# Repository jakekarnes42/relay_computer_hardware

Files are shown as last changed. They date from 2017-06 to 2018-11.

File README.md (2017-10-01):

# Relay Computer (Hardware)
This repo contains the hardware information for a computer constructed out of relays. Its software companion project can be found [here](https://github.com/jakekarnes42/relay_computer_software). 

This project has taken much of its inspiration from Dr. Harry Porter's [relay computer](https://web.cecs.pdx.edu/~harry/Relay/RelayPaper.htm). While there are many architectural similarities, there are also significant differences which are described below. This project wouldn't have been possible for me without his clear notes and thorough explanations. 

The documentation is still a work in progress and likely to change as the design itself changes. 

## Hardware Architecture Notes:
### Registers:
All registers are 16 bits (1 word) wide. There are 11 registers total.

There are 5 general purpose registers: AX, BX, CX, DX, and EX. These registers don’t have any special functions (e.g. stack operations). 

There are 2 stack-pointer registers: SP and RP. These are used with the PUSH, POP, CALL and CALL_I operations. These registers point to memory locations of the current top of the stack. When a value is pushed onto the stack, the register is first incremented, and then the value is copied to that location in memory. When a value is to popped off the stack, the value in the memory address pointed to by the stack register is returned, and then the stack register is decremented. 

There is one program counter: PC. The PC contains the address of the next
instruction to be executed. In some computers, this register is called the “Instruction Pointer”.

There is one instruction register: INST. During instruction execution, INST contains the current instruction being executed.

There are two temporary registers: TMP1 and TMP2. These are considered “scratch pads” and their values are not to be considered consistent between instructions. These are the inputs to the ALU. 
### Condition Codes:
####  Zero: 
True (1) when the ALU output is zero. If any bit of the ALU output is 1, then this flag will be set to false (0).
Sign:
True (1) when the highest (16th) bit of the ALU output is 1. That is, if considered as a signed value, the flag is set to true when the ALU output is negative. 
#### Overflow:
True (1) when the ALU output produced a signed overflow. Overflow occurs if the addition of two positive numbers gives a negative number and if the addition of two negative numbers gives a positive. That is, you need to compare the MSB of the operands and the answer. If the sign of the operands and the sign of the answer don't match, the overflow flag is turned on. The output is too large or too small to store in 16 bits (using two’s-complement format)

If the ALU isn’t performing ADD, INC, or DEC, this should be false (0), since it doesn’t really make sense for a logic operation to result in overflow
#### Carry:
This is the value of the 17th bit of the output. If performing unsigned addition, this indicates that the result was too large to fit into a 16-bit word (i.e. too large to fit into a register). If performing subtraction (e.g. a−b), the carry bit is equivalent to a < b.

If the ALU isn’t performing ADD, INC, or DEC, this should be false (0).
Memory:
The computer has 1,048,576 bits (1 Mb) of random access memory. This is organized as 65,536 (64k) words of 16 bits each. This results in 16-bit addresses, each storing a 16-bit word. 

The memory is non-volatile, i.e. the memory isn’t cleared when the computer is powered off. The program can be loaded into memory separately before the computer is powered on. 
#### ALU:
The ALU takes 3 inputs: a 3-bit function code, and two 16-bit operands. The ALU produces 5 outputs: the zero flag, the sign flag, the overflow flag, the carry flag, and a 16-bit result. 

The 3 bit function code is interpreted as follows:
* 000: INC
* 001: DEC
* 010: ADD
* 011: AND
* 100: OR
* 101: XOR
* 110: NOT
* 111: SHL

##### Design: 
4-bit ALU Schematic

## Changes from Harry’s Design
### Definite
* Dedicated stack register(s)
* I/O device support
* Four ALU-set flags:
1.  s (sign)
2.  z (zero)
3. c (carry)
4.  o (overflow) ** ← NEW**
### Maybe
* TMP registers?
   These aren’t addressable by themselves, but are intermediates for other operations. For example, two TMP registers could be used as the inputs to the ALU. The real operand(s) would be moved into the TMP registers before the ALU is engaged
* Split ALU: single operand instructions vs double operand instructions
   The Arithmetic side should support ADD, INC, DEC. These can all use the Zuse adder with different input C, or 1, or -1
   The Logic side should support AND, OR, XOR, NOT, ROL

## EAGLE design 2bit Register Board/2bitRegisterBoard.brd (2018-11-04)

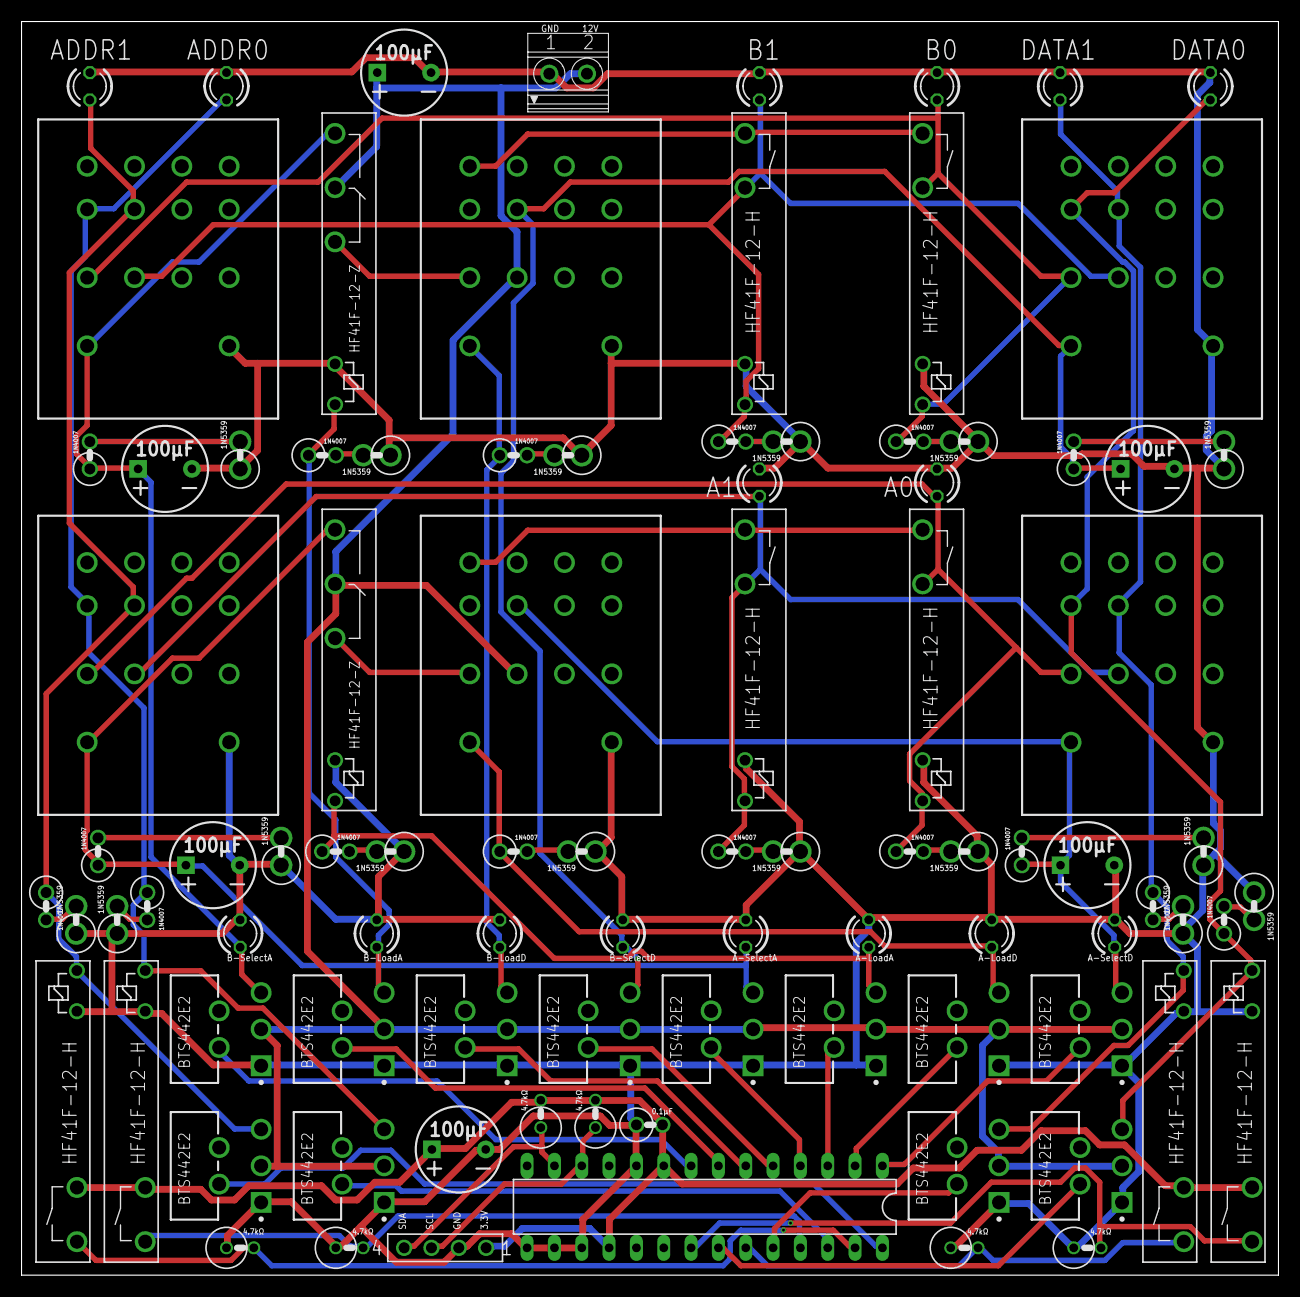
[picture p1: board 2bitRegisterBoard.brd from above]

Board: 2 copper layers, 116.8 x 116.5 mm, 92 parts (0 on the bottom side), 57 nets.

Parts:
12V_PWR_BLK:C1: 100uF; CPOL-RADIAL-5MM-8MM
12V_PWR_BLK:PWR: PWR_BLK; 1751248
COMP_SIGNALS1:3V3_TO_12_1BIT0:U1, COMP_SIGNALS1:3V3_TO_12_1BIT1:U1, COMP_SIGNALS1:3V3_TO_12_1BIT2:U1, COMP_SIGNALS1:3V3_TO_12_1BIT3:U1, COMP_SIGNALS1:3V3_TO_12_1BIT4:U1, COMP_SIGNALS1:3V3_TO_12_1BIT5:U1, COMP_SIGNALS1:3V3_TO_12_1BIT6:U1, COMP_SIGNALS1:3V3_TO_12_1BIT7:U1, COMP_SIGNALS1:DUAL_12V⇆3V3_1BIT0:3V3_TO_12_1BIT1:U1, COMP_SIGNALS1:DUAL_12V⇆3V3_1BIT1:3V3_TO_12_1BIT1:U1, COMP_SIGNALS1:DUAL_12V⇆3V3_1BIT2:3V3_TO_12_1BIT1:U1, COMP_SIGNALS1:DUAL_12V⇆3V3_1BIT3:3V3_TO_12_1BIT1:U1: BTS442E2; TO170P440X1000X1975-5B
COMP_SIGNALS1:DUAL_12V⇆3V3_1BIT0:12V_TO_3V3_1BIT1:D5, COMP_SIGNALS1:DUAL_12V⇆3V3_1BIT1:12V_TO_3V3_1BIT1:D5, COMP_SIGNALS1:DUAL_12V⇆3V3_1BIT2:12V_TO_3V3_1BIT1:D5, COMP_SIGNALS1:DUAL_12V⇆3V3_1BIT3:12V_TO_3V3_1BIT1:D5: 1N4007; RAD2,5
COMP_SIGNALS1:DUAL_12V⇆3V3_1BIT0:12V_TO_3V3_1BIT1:D6, COMP_SIGNALS1:DUAL_12V⇆3V3_1BIT1:12V_TO_3V3_1BIT1:D6, COMP_SIGNALS1:DUAL_12V⇆3V3_1BIT2:12V_TO_3V3_1BIT1:D6, COMP_SIGNALS1:DUAL_12V⇆3V3_1BIT3:12V_TO_3V3_1BIT1:D6: 1N5359VERT_SML; RAD2.5_D2
COMP_SIGNALS1:DUAL_12V⇆3V3_1BIT0:12V_TO_3V3_1BIT1:K3, COMP_SIGNALS1:DUAL_12V⇆3V3_1BIT1:12V_TO_3V3_1BIT1:K3, COMP_SIGNALS1:DUAL_12V⇆3V3_1BIT2:12V_TO_3V3_1BIT1:K3, COMP_SIGNALS1:DUAL_12V⇆3V3_1BIT3:12V_TO_3V3_1BIT1:K3: HF41F-12-H
COMP_SIGNALS1:I2C_IO:C1: 100uF; CPOL-RADIAL-5MM-8MM
COMP_SIGNALS1:I2C_IO:C2: 0.1UF; VERT_CAP
COMP_SIGNALS1:I2C_IO:IC1: MCP23017SP; DIL28-3
COMP_SIGNALS1:I2C_IO:R1, COMP_SIGNALS1:I2C_IO:R2, COMP_SIGNALS1:I2C_IO:R3, COMP_SIGNALS1:I2C_IO:R4, COMP_SIGNALS1:I2C_IO:R5, COMP_SIGNALS1:I2C_IO:R6: 4.7KOHM; RAD2.5_RES
COMP_SIGNALS1:I2C_IO:SV1: FE04-1
COMP_SIGNALS1:LED0, COMP_SIGNALS1:LED1, COMP_SIGNALS1:LED2, COMP_SIGNALS1:LED3, COMP_SIGNALS1:LED4, COMP_SIGNALS1:LED5, COMP_SIGNALS1:LED6, COMP_SIGNALS1:LED7, COMP_SIGNALS1:LED8, COMP_SIGNALS1:LED9, COMP_SIGNALS1:LED10, COMP_SIGNALS1:LED11: LED3MM
REGISTER_A:C1, REGISTER_A:C2: 100uF; CPOL-RADIAL-5MM-8MM
REGISTER_A:D1, REGISTER_A:D3, REGISTER_A:D7, REGISTER_A:D9: 1N4007; RAD2,5
REGISTER_A:D2, REGISTER_A:D4, REGISTER_A:D8, REGISTER_A:D10: 1N5359VERT_SML; RAD2.5_D2
REGISTER_A:ENABLE_ADDRESS:D1: 1N4007; RAD2,5
REGISTER_A:ENABLE_ADDRESS:D2: 1N5359VERT_SML; RAD2.5_D2
REGISTER_A:ENABLE_ADDRESS:K1: PY14-02
REGISTER_A:ENABLE_DATA:D1: 1N4007; RAD2,5
REGISTER_A:ENABLE_DATA:D2: 1N5359VERT_SML; RAD2.5_D2
REGISTER_A:ENABLE_DATA:K1: PY14-02
REGISTER_A:K1: HF41F-12-Z
REGISTER_A:K2: PY14-02
REGISTER_A:K4, REGISTER_A:K5: HF41F-12-H
REGISTER_A:LED2, REGISTER_A:LED3: LED3MM
REGISTER_B:C1, REGISTER_B:C2: 100uF; CPOL-RADIAL-5MM-8MM
REGISTER_B:D1, REGISTER_B:D3, REGISTER_B:D7, REGISTER_B:D9: 1N4007; RAD2,5
REGISTER_B:D2, REGISTER_B:D4, REGISTER_B:D8, REGISTER_B:D10: 1N5359VERT_SML; RAD2.5_D2
REGISTER_B:ENABLE_ADDRESS:D1: 1N4007; RAD2,5
REGISTER_B:ENABLE_ADDRESS:D2: 1N5359VERT_SML; RAD2.5_D2
REGISTER_B:ENABLE_ADDRESS:K1: PY14-02
REGISTER_B:ENABLE_DATA:D1: 1N4007; RAD2,5
REGISTER_B:ENABLE_DATA:D2: 1N5359VERT_SML; RAD2.5_D2
REGISTER_B:ENABLE_DATA:K1: PY14-02
REGISTER_B:K1: HF41F-12-Z
REGISTER_B:K2: PY14-02
REGISTER_B:K4, REGISTER_B:K5: HF41F-12-H
REGISTER_B:LED2, REGISTER_B:LED3: LED3MM

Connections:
+3V3: COMP_SIGNALS1:DUAL_12V⇆3V3_1BIT0:12V_TO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.4, COMP_SIGNALS1:DUAL_12V⇆3V3_1BIT1:12V_TO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.4, COMP_SIGNALS1:DUAL_12V⇆3V3_1BIT2:12V_TO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.4, COMP_SIGNALS1:DUAL_12V⇆3V3_1BIT3:12V_TO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.4, COMP_SIGNALS1:I2C_IO:C1.1, COMP_SIGNALS1:I2C_IO:C2.A, COMP_SIGNALS1:I2C_IO:IC1.9, COMP_SIGNALS1:I2C_IO:IC1.18, COMP_SIGNALS1:I2C_IO:R1.A, COMP_SIGNALS1:I2C_IO:R2.A, COMP_SIGNALS1:I2C_IO:SV1.1
+12V: 12V_PWR_BLK:C1.1, 12V_PWR_BLK:PWR.2, COMP_SIGNALS1:3V3_TO_12_1BIT0:U1.3, COMP_SIGNALS1:3V3_TO_12_1BIT1:U1.3, COMP_SIGNALS1:3V3_TO_12_1BIT2:U1.3, COMP_SIGNALS1:3V3_TO_12_1BIT3:U1.3, COMP_SIGNALS1:3V3_TO_12_1BIT4:U1.3, COMP_SIGNALS1:3V3_TO_12_1BIT5:U1.3, COMP_SIGNALS1:3V3_TO_12_1BIT6:U1.3, COMP_SIGNALS1:3V3_TO_12_1BIT7:U1.3, COMP_SIGNALS1:DUAL_12V⇆3V3_1BIT0:3V3_TO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.3, COMP_SIGNALS1:DUAL_12V⇆3V3_1BIT1:3V3_TO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.3, COMP_SIGNALS1:DUAL_12V⇆3V3_1BIT2:3V3_TO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.3, COMP_SIGNALS1:DUAL_12V⇆3V3_1BIT3:3V3_TO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.3, REGISTER_A:K1.4, REGISTER_A:K2.31, REGISTER_B:K1.4, REGISTER_B:K2.31
A0: COMP_SIGNALS1:DUAL_12V⇆3V3_1BIT2:3V3_TO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.5, COMP_SIGNALS1:DUAL_12V⇆3V3_1BIT2:12V_TO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.C, COMP_SIGNALS1:DUAL_12V⇆3V3_1BIT2:12V_TO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.1, COMP_SIGNALS1:LED10.A, REGISTER_A:ENABLE_ADDRESS:K1.44, REGISTER_B:ENABLE_ADDRESS:K1.44
A1: COMP_SIGNALS1:DUAL_12V⇆3V3_1BIT3:3V3_TO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.5, COMP_SIGNALS1:DUAL_12V⇆3V3_1BIT3:12V_TO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.C, COMP_SIGNALS1:DUAL_12V⇆3V3_1BIT3:12V_TO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.1, COMP_SIGNALS1:LED11.A, REGISTER_A:ENABLE_ADDRESS:K1.34, REGISTER_B:ENABLE_ADDRESS:K1.34
COMP_SIGNALS1:DUAL_12V⇆3V3_1BIT0:12V_TO_3V3_1BIT1:D$3: COMP_SIGNALS1:DUAL_12V⇆3V3_1BIT0:12V_TO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.A, COMP_SIGNALS1:DUAL_12V⇆3V3_1BIT0:12V_TO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.A
COMP_SIGNALS1:DUAL_12V⇆3V3_1BIT1:12V_TO_3V3_1BIT1:D$3: COMP_SIGNALS1:DUAL_12V⇆3V3_1BIT1:12V_TO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.A, COMP_SIGNALS1:DUAL_12V⇆3V3_1BIT1:12V_TO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.A
COMP_SIGNALS1:DUAL_12V⇆3V3_1BIT2:12V_TO_3V3_1BIT1:D$3: COMP_SIGNALS1:DUAL_12V⇆3V3_1BIT2:12V_TO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.A, COMP_SIGNALS1:DUAL_12V⇆3V3_1BIT2:12V_TO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.A
COMP_SIGNALS1:DUAL_12V⇆3V3_1BIT3:12V_TO_3V3_1BIT1:D$3: COMP_SIGNALS1:DUAL_12V⇆3V3_1BIT3:12V_TO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.A, COMP_SIGNALS1:DUAL_12V⇆3V3_1BIT3:12V_TO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.A
COMP_SIGNALS1:I2C_IO:SCL: COMP_SIGNALS1:I2C_IO:IC1.12, COMP_SIGNALS1:I2C_IO:R1.C, COMP_SIGNALS1:I2C_IO:SV1.3
COMP_SIGNALS1:I2C_IO:SDA: COMP_SIGNALS1:I2C_IO:IC1.13, COMP_SIGNALS1:I2C_IO:R2.C, COMP_SIGNALS1:I2C_IO:SV1.4
COMP_SIGNALS1:N$5: COMP_SIGNALS1:DUAL_12V⇆3V3_1BIT3:3V3_TO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.2, COMP_SIGNALS1:I2C_IO:IC1.28
COMP_SIGNALS1:N$6: COMP_SIGNALS1:DUAL_12V⇆3V3_1BIT3:12V_TO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.5, COMP_SIGNALS1:I2C_IO:IC1.27, COMP_SIGNALS1:I2C_IO:R6.A
COMP_SIGNALS1:N$7: COMP_SIGNALS1:DUAL_12V⇆3V3_1BIT2:3V3_TO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.2, COMP_SIGNALS1:I2C_IO:IC1.26
COMP_SIGNALS1:N$8: COMP_SIGNALS1:DUAL_12V⇆3V3_1BIT2:12V_TO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.5, COMP_SIGNALS1:I2C_IO:IC1.25, COMP_SIGNALS1:I2C_IO:R5.A
COMP_SIGNALS1:N$9: COMP_SIGNALS1:DUAL_12V⇆3V3_1BIT1:3V3_TO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.2, COMP_SIGNALS1:I2C_IO:IC1.24
COMP_SIGNALS1:N$10: COMP_SIGNALS1:DUAL_12V⇆3V3_1BIT1:12V_TO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.5, COMP_SIGNALS1:I2C_IO:IC1.23, COMP_SIGNALS1:I2C_IO:R4.A
COMP_SIGNALS1:N$11: COMP_SIGNALS1:DUAL_12V⇆3V3_1BIT0:3V3_TO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.2, COMP_SIGNALS1:I2C_IO:IC1.22
COMP_SIGNALS1:N$12: COMP_SIGNALS1:DUAL_12V⇆3V3_1BIT0:12V_TO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.5, COMP_SIGNALS1:I2C_IO:IC1.21, COMP_SIGNALS1:I2C_IO:R3.A
COMP_SIGNALS1:N$13: COMP_SIGNALS1:3V3_TO_12_1BIT7:U1.2, COMP_SIGNALS1:I2C_IO:IC1.8
COMP_SIGNALS1:N$14: COMP_SIGNALS1:3V3_TO_12_1BIT6:U1.2, COMP_SIGNALS1:I2C_IO:IC1.7
COMP_SIGNALS1:N$15: COMP_SIGNALS1:3V3_TO_12_1BIT5:U1.2, COMP_SIGNALS1:I2C_IO:IC1.6
COMP_SIGNALS1:N$16: COMP_SIGNALS1:3V3_TO_12_1BIT4:U1.2, COMP_SIGNALS1:I2C_IO:IC1.5
COMP_SIGNALS1:N$17: COMP_SIGNALS1:3V3_TO_12_1BIT3:U1.2, COMP_SIGNALS1:I2C_IO:IC1.4
COMP_SIGNALS1:N$18: COMP_SIGNALS1:3V3_TO_12_1BIT2:U1.2, COMP_SIGNALS1:I2C_IO:IC1.3
COMP_SIGNALS1:N$19: COMP_SIGNALS1:3V3_TO_12_1BIT1:U1.2, COMP_SIGNALS1:I2C_IO:IC1.2
COMP_SIGNALS1:N$20: COMP_SIGNALS1:3V3_TO_12_1BIT0:U1.2, COMP_SIGNALS1:I2C_IO:IC1.1
D0: COMP_SIGNALS1:DUAL_12V⇆3V3_1BIT0:3V3_TO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.5, COMP_SIGNALS1:DUAL_12V⇆3V3_1BIT0:12V_TO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.C, COMP_SIGNALS1:DUAL_12V⇆3V3_1BIT0:12V_TO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.1, COMP_SIGNALS1:LED8.A, REGISTER_A:ENABLE_DATA:K1.44, REGISTER_B:ENABLE_DATA:K1.44
D1: COMP_SIGNALS1:DUAL_12V⇆3V3_1BIT1:3V3_TO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.5, COMP_SIGNALS1:DUAL_12V⇆3V3_1BIT1:12V_TO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.C, COMP_SIGNALS1:DUAL_12V⇆3V3_1BIT1:12V_TO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.1, COMP_SIGNALS1:LED9.A, REGISTER_A:ENABLE_DATA:K1.34, REGISTER_B:ENABLE_DATA:K1.34
GND: 12V_PWR_BLK:C1.2, 12V_PWR_BLK:PWR.1, COMP_SIGNALS1:3V3_TO_12_1BIT0:U1.1, COMP_SIGNALS1:3V3_TO_12_1BIT1:U1.1, COMP_SIGNALS1:3V3_TO_12_1BIT2:U1.1, COMP_SIGNALS1:3V3_TO_12_1BIT3:U1.1, COMP_SIGNALS1:3V3_TO_12_1BIT4:U1.1, COMP_SIGNALS1:3V3_TO_12_1BIT5:U1.1, COMP_SIGNALS1:3V3_TO_12_1BIT6:U1.1, COMP_SIGNALS1:3V3_TO_12_1BIT7:U1.1, COMP_SIGNALS1:DUAL_12V⇆3V3_1BIT0:3V3_TO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.1, COMP_SIGNALS1:DUAL_12V⇆3V3_1BIT0:12V_TO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.C, COMP_SIGNALS1:DUAL_12V⇆3V3_1BIT0:12V_TO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.2, COMP_SIGNALS1:DUAL_12V⇆3V3_1BIT1:3V3_TO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.1, COMP_SIGNALS1:DUAL_12V⇆3V3_1BIT1:12V_TO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.C, COMP_SIGNALS1:DUAL_12V⇆3V3_1BIT1:12V_TO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.2, COMP_SIGNALS1:DUAL_12V⇆3V3_1BIT2:3V3_TO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.1, COMP_SIGNALS1:DUAL_12V⇆3V3_1BIT2:12V_TO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.C, COMP_SIGNALS1:DUAL_12V⇆3V3_1BIT2:12V_TO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.2, COMP_SIGNALS1:DUAL_12V⇆3V3_1BIT3:3V3_TO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.1, COMP_SIGNALS1:DUAL_12V⇆3V3_1BIT3:12V_TO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.C, COMP_SIGNALS1:DUAL_12V⇆3V3_1BIT3:12V_TO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.2, COMP_SIGNALS1:I2C_IO:C1.2, COMP_SIGNALS1:I2C_IO:C2.C, COMP_SIGNALS1:I2C_IO:IC1.10, COMP_SIGNALS1:I2C_IO:IC1.15, COMP_SIGNALS1:I2C_IO:IC1.16, COMP_SIGNALS1:I2C_IO:IC1.17, COMP_SIGNALS1:I2C_IO:R3.C, COMP_SIGNALS1:I2C_IO:R4.C, COMP_SIGNALS1:I2C_IO:R5.C, COMP_SIGNALS1:I2C_IO:R6.C, COMP_SIGNALS1:I2C_IO:SV1.2, COMP_SIGNALS1:LED0.K, COMP_SIGNALS1:LED1.K, COMP_SIGNALS1:LED2.K, COMP_SIGNALS1:LED3.K, COMP_SIGNALS1:LED4.K, COMP_SIGNALS1:LED5.K, COMP_SIGNALS1:LED6.K, COMP_SIGNALS1:LED7.K, COMP_SIGNALS1:LED8.K, COMP_SIGNALS1:LED9.K, COMP_SIGNALS1:LED10.K, COMP_SIGNALS1:LED11.K, REGISTER_A:C1.2, REGISTER_A:C2.2, REGISTER_A:D2.C, REGISTER_A:D4.C, REGISTER_A:D8.C, REGISTER_A:D10.C, REGISTER_A:ENABLE_ADDRESS:D2.C, REGISTER_A:ENABLE_ADDRESS:K1.A1, REGISTER_A:ENABLE_DATA:D2.C, REGISTER_A:ENABLE_DATA:K1.A1, REGISTER_A:K1.2, REGISTER_A:K2.A1, REGISTER_A:K4.2, REGISTER_A:K5.2, REGISTER_A:LED2.K, REGISTER_A:LED3.K, REGISTER_B:C1.2, REGISTER_B:C2.2, REGISTER_B:D2.C, REGISTER_B:D4.C, REGISTER_B:D8.C, REGISTER_B:D10.C, REGISTER_B:ENABLE_ADDRESS:D2.C, REGISTER_B:ENABLE_ADDRESS:K1.A1, REGISTER_B:ENABLE_DATA:D2.C, REGISTER_B:ENABLE_DATA:K1.A1, REGISTER_B:K1.2, REGISTER_B:K2.A1, REGISTER_B:K4.2, REGISTER_B:K5.2, REGISTER_B:LED2.K, REGISTER_B:LED3.K
R0_LOADA: COMP_SIGNALS1:3V3_TO_12_1BIT2:U1.5, COMP_SIGNALS1:LED2.A, REGISTER_A:D1.C, REGISTER_A:K1.1
R0_LOADD: COMP_SIGNALS1:3V3_TO_12_1BIT1:U1.5, COMP_SIGNALS1:LED1.A, REGISTER_A:D3.C, REGISTER_A:K2.A2
R0_SELECTA: COMP_SIGNALS1:3V3_TO_12_1BIT3:U1.5, COMP_SIGNALS1:LED3.A, REGISTER_A:C1.1, REGISTER_A:ENABLE_ADDRESS:D1.C, REGISTER_A:ENABLE_ADDRESS:K1.A2, REGISTER_A:K1.5
R0_SELECTD: COMP_SIGNALS1:3V3_TO_12_1BIT0:U1.5, COMP_SIGNALS1:LED0.A, REGISTER_A:C2.1, REGISTER_A:ENABLE_DATA:D1.C, REGISTER_A:ENABLE_DATA:K1.A2, REGISTER_A:K2.34
R1_LOADA: COMP_SIGNALS1:3V3_TO_12_1BIT6:U1.5, COMP_SIGNALS1:LED6.A, REGISTER_B:D1.C, REGISTER_B:K1.1
R1_LOADD: COMP_SIGNALS1:3V3_TO_12_1BIT5:U1.5, COMP_SIGNALS1:LED5.A, REGISTER_B:D3.C, REGISTER_B:K2.A2
R1_SELECTA: COMP_SIGNALS1:3V3_TO_12_1BIT7:U1.5, COMP_SIGNALS1:LED7.A, REGISTER_B:C1.1, REGISTER_B:ENABLE_ADDRESS:D1.C, REGISTER_B:ENABLE_ADDRESS:K1.A2, REGISTER_B:K1.5
R1_SELECTD: COMP_SIGNALS1:3V3_TO_12_1BIT4:U1.5, COMP_SIGNALS1:LED4.A, REGISTER_B:C2.1, REGISTER_B:ENABLE_DATA:D1.C, REGISTER_B:ENABLE_DATA:K1.A2, REGISTER_B:K2.34
REGISTER_A:D$1: REGISTER_A:D1.A, REGISTER_A:D2.A
REGISTER_A:D$2: REGISTER_A:D3.A, REGISTER_A:D4.A
REGISTER_A:D$4: REGISTER_A:D7.A, REGISTER_A:D8.A
REGISTER_A:D$5: REGISTER_A:D9.A, REGISTER_A:D10.A
REGISTER_A:ENABLE_ADDRESS:D$1: REGISTER_A:ENABLE_ADDRESS:D1.A, REGISTER_A:ENABLE_ADDRESS:D2.A
REGISTER_A:ENABLE_DATA:D$1: REGISTER_A:ENABLE_DATA:D1.A, REGISTER_A:ENABLE_DATA:D2.A
REGISTER_A:HOLD: REGISTER_A:K2.42, REGISTER_A:K4.5, REGISTER_A:K5.5
REGISTER_A:N$1: REGISTER_A:K1.3, REGISTER_A:K2.41
REGISTER_A:R0: REGISTER_A:D9.C, REGISTER_A:ENABLE_ADDRESS:K1.41, REGISTER_A:ENABLE_DATA:K1.41, REGISTER_A:K5.1, REGISTER_A:K5.4, REGISTER_A:LED2.A
REGISTER_A:R1: REGISTER_A:D7.C, REGISTER_A:ENABLE_ADDRESS:K1.31, REGISTER_A:ENABLE_DATA:K1.31, REGISTER_A:K4.1, REGISTER_A:K4.4, REGISTER_A:LED3.A
REGISTER_B:D$1: REGISTER_B:D1.A, REGISTER_B:D2.A
REGISTER_B:D$2: REGISTER_B:D3.A, REGISTER_B:D4.A
REGISTER_B:D$4: REGISTER_B:D7.A, REGISTER_B:D8.A
REGISTER_B:D$5: REGISTER_B:D9.A, REGISTER_B:D10.A
REGISTER_B:ENABLE_ADDRESS:D$1: REGISTER_B:ENABLE_ADDRESS:D1.A, REGISTER_B:ENABLE_ADDRESS:D2.A
REGISTER_B:ENABLE_DATA:D$1: REGISTER_B:ENABLE_DATA:D1.A, REGISTER_B:ENABLE_DATA:D2.A
REGISTER_B:HOLD: REGISTER_B:K2.42, REGISTER_B:K4.5, REGISTER_B:K5.5
REGISTER_B:N$1: REGISTER_B:K1.3, REGISTER_B:K2.41
REGISTER_B:R0: REGISTER_B:D9.C, REGISTER_B:ENABLE_ADDRESS:K1.41, REGISTER_B:ENABLE_DATA:K1.41, REGISTER_B:K5.1, REGISTER_B:K5.4, REGISTER_B:LED2.A
REGISTER_B:R1: REGISTER_B:D7.C, REGISTER_B:ENABLE_ADDRESS:K1.31, REGISTER_B:ENABLE_DATA:K1.31, REGISTER_B:K4.1, REGISTER_B:K4.4, REGISTER_B:LED3.A

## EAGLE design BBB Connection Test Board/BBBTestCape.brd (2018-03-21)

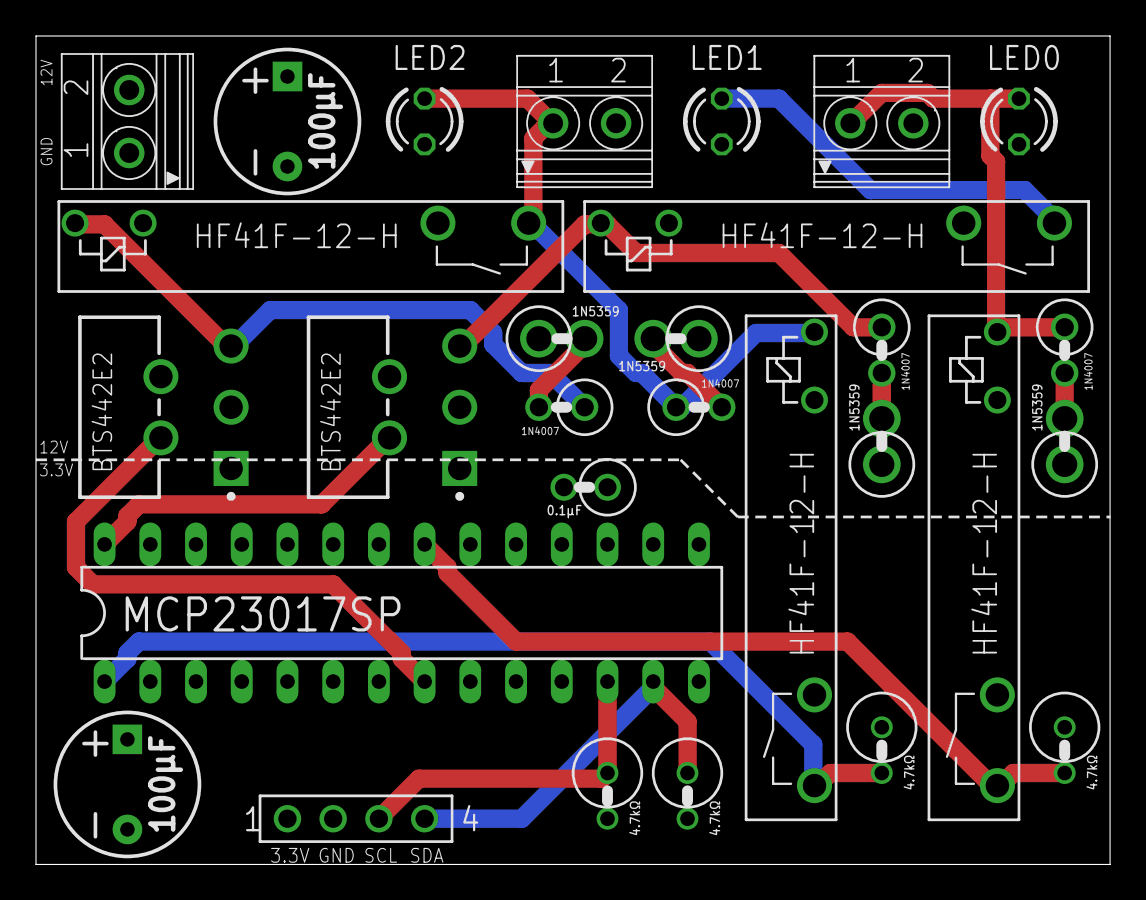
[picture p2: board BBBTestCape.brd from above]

Board: 4 copper layers, 59.7 x 46.0 mm, 29 parts (0 on the bottom side), 19 nets.

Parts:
3V3_TO_12_1BIT1:D3, 12V_TO_3V3_1BIT1:D5: 1N4007; RAD2,5
3V3_TO_12_1BIT1:D4, 12V_TO_3V3_1BIT1:D6: 1N5359VERT_SML; RAD2.5_D2
3V3_TO_12_1BIT1:K2, 12V_TO_3V3_1BIT1:K3: HF41F-12-H
3V3_TO_12_1BIT1:U1: BTS442E2; TO170P440X1000X1975-5B
12V_PWR_BLK:C1: 100uF; CPOL-RADIAL-5MM-8MM
12V_PWR_BLK:PWR: PWR_BLK; 1751248
BBB_IO1:C1: 100uF; CPOL-RADIAL-5MM-8MM
BBB_IO1:C2: 0.1UF; VERT_CAP
BBB_IO1:IC1: MCP23017SP; DIL28-3
BBB_IO1:R1, BBB_IO1:R2, BBB_IO1:R3, BBB_IO1:R4: 4.7KOHM; RAD2.5_RES
BBB_IO1:SV1: FE04-1
DUAL_12V⇆3V3_1BIT1:3V3_TO_12_1BIT1:D3, DUAL_12V⇆3V3_1BIT1:12V_TO_3V3_1BIT1:D5: 1N4007; RAD2,5
DUAL_12V⇆3V3_1BIT1:3V3_TO_12_1BIT1:D4, DUAL_12V⇆3V3_1BIT1:12V_TO_3V3_1BIT1:D6: 1N5359VERT_SML; RAD2.5_D2
DUAL_12V⇆3V3_1BIT1:3V3_TO_12_1BIT1:K2, DUAL_12V⇆3V3_1BIT1:12V_TO_3V3_1BIT1:K3: HF41F-12-H
DUAL_12V⇆3V3_1BIT1:3V3_TO_12_1BIT1:U1: BTS442E2; TO170P440X1000X1975-5B
LED0, LED1, LED2: LED3MM
X0, X1: SWTCH_BLCK; 1751248

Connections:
3V3_TO_12_1BIT1:D$2: 3V3_TO_12_1BIT1:D3.A, 3V3_TO_12_1BIT1:D4.A
3V3_TO_12_1BIT1:N$1: 3V3_TO_12_1BIT1:D3.C, 3V3_TO_12_1BIT1:K2.1, 3V3_TO_12_1BIT1:U1.5
12V_TO_3V3_1BIT1:D$3: 12V_TO_3V3_1BIT1:D5.A, 12V_TO_3V3_1BIT1:D6.A
+3V3: 12V_TO_3V3_1BIT1:K3.4, BBB_IO1:C1.1, BBB_IO1:C2.A, BBB_IO1:IC1.9, BBB_IO1:IC1.18, BBB_IO1:R1.A, BBB_IO1:R2.A, BBB_IO1:SV1.1, DUAL_12V⇆3V3_1BIT1:12V_TO_3V3_1BIT1:K3.4
+12V: 3V3_TO_12_1BIT1:K2.4, 3V3_TO_12_1BIT1:U1.3, 12V_PWR_BLK:C1.1, 12V_PWR_BLK:PWR.2, DUAL_12V⇆3V3_1BIT1:3V3_TO_12_1BIT1:K2.4, DUAL_12V⇆3V3_1BIT1:3V3_TO_12_1BIT1:U1.3, X0.2, X1.2
BBB_IO1:SCL: BBB_IO1:IC1.12, BBB_IO1:R1.C, BBB_IO1:SV1.3
BBB_IO1:SDA: BBB_IO1:IC1.13, BBB_IO1:R2.C, BBB_IO1:SV1.4
DUAL_12V⇆3V3_1BIT1:3V3_TO_12_1BIT1:D$2: DUAL_12V⇆3V3_1BIT1:3V3_TO_12_1BIT1:D3.A, DUAL_12V⇆3V3_1BIT1:3V3_TO_12_1BIT1:D4.A
DUAL_12V⇆3V3_1BIT1:3V3_TO_12_1BIT1:N$1: DUAL_12V⇆3V3_1BIT1:3V3_TO_12_1BIT1:D3.C, DUAL_12V⇆3V3_1BIT1:3V3_TO_12_1BIT1:K2.1, DUAL_12V⇆3V3_1BIT1:3V3_TO_12_1BIT1:U1.5
DUAL_12V⇆3V3_1BIT1:12V_TO_3V3_1BIT1:D$3: DUAL_12V⇆3V3_1BIT1:12V_TO_3V3_1BIT1:D5.A, DUAL_12V⇆3V3_1BIT1:12V_TO_3V3_1BIT1:D6.A
GND: 3V3_TO_12_1BIT1:D4.C, 3V3_TO_12_1BIT1:K2.2, 12V_PWR_BLK:C1.2, 12V_PWR_BLK:PWR.1, 12V_TO_3V3_1BIT1:D6.C, 12V_TO_3V3_1BIT1:K3.2, DUAL_12V⇆3V3_1BIT1:3V3_TO_12_1BIT1:D4.C, DUAL_12V⇆3V3_1BIT1:3V3_TO_12_1BIT1:K2.2, DUAL_12V⇆3V3_1BIT1:12V_TO_3V3_1BIT1:D6.C, DUAL_12V⇆3V3_1BIT1:12V_TO_3V3_1BIT1:K3.2, LED0.K, LED1.K, LED2.K
GND3: 3V3_TO_12_1BIT1:U1.1, BBB_IO1:C1.2, BBB_IO1:C2.C, BBB_IO1:IC1.10, BBB_IO1:IC1.15, BBB_IO1:IC1.16, BBB_IO1:IC1.17, BBB_IO1:R3.C, BBB_IO1:R4.C, BBB_IO1:SV1.2, DUAL_12V⇆3V3_1BIT1:3V3_TO_12_1BIT1:U1.1
unnamed: 3V3_TO_12_1BIT1:K2.5, LED1.A
unnamed: 12V_TO_3V3_1BIT1:D5.C, 12V_TO_3V3_1BIT1:K3.1, LED0.A, X0.1
unnamed: DUAL_12V⇆3V3_1BIT1:3V3_TO_12_1BIT1:K2.5, DUAL_12V⇆3V3_1BIT1:12V_TO_3V3_1BIT1:D5.C, DUAL_12V⇆3V3_1BIT1:12V_TO_3V3_1BIT1:K3.1, LED2.A, X1.1
unnamed: BBB_IO1:IC1.8, DUAL_12V⇆3V3_1BIT1:3V3_TO_12_1BIT1:U1.2
unnamed: BBB_IO1:IC1.1, BBB_IO1:R4.A, DUAL_12V⇆3V3_1BIT1:12V_TO_3V3_1BIT1:K3.5
unnamed: 3V3_TO_12_1BIT1:U1.2, BBB_IO1:IC1.28
unnamed: 12V_TO_3V3_1BIT1:K3.5, BBB_IO1:IC1.21, BBB_IO1:R3.A

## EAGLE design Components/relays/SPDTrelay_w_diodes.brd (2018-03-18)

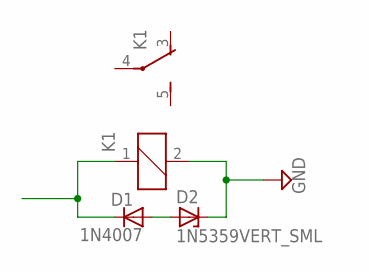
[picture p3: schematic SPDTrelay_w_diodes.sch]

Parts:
D1: 1N4007; RAD2,5
D2: 1N5359VERT_SML; RAD2.5_D2
K1: HF41F-12-Z

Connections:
D$1: D1.A, D2.A
GND: D2.C, K1.2
IN: D1.C, K1.1

Board: 2 copper layers, 3 parts (0 on the bottom side), 3 nets, no tracks yet.

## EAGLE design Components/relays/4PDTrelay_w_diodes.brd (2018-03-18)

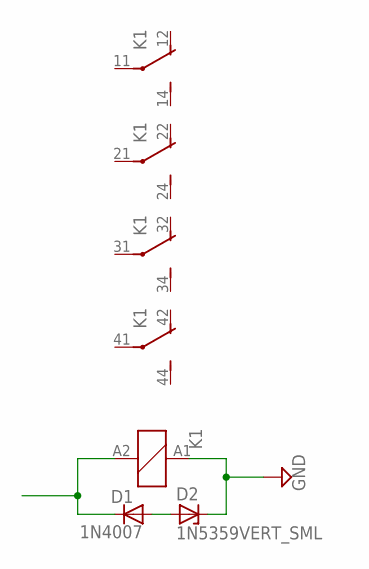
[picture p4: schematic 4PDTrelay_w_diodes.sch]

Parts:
D1: 1N4007; RAD2,5
D2: 1N5359VERT_SML; RAD2.5_D2
K1: PY14-02

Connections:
D$1: D1.A, D2.A
GND: D2.C, K1.A1 (1)
IN: D1.C, K1.A2 (2)

Board: 2 copper layers, 3 parts (0 on the bottom side), 3 nets, no tracks yet.

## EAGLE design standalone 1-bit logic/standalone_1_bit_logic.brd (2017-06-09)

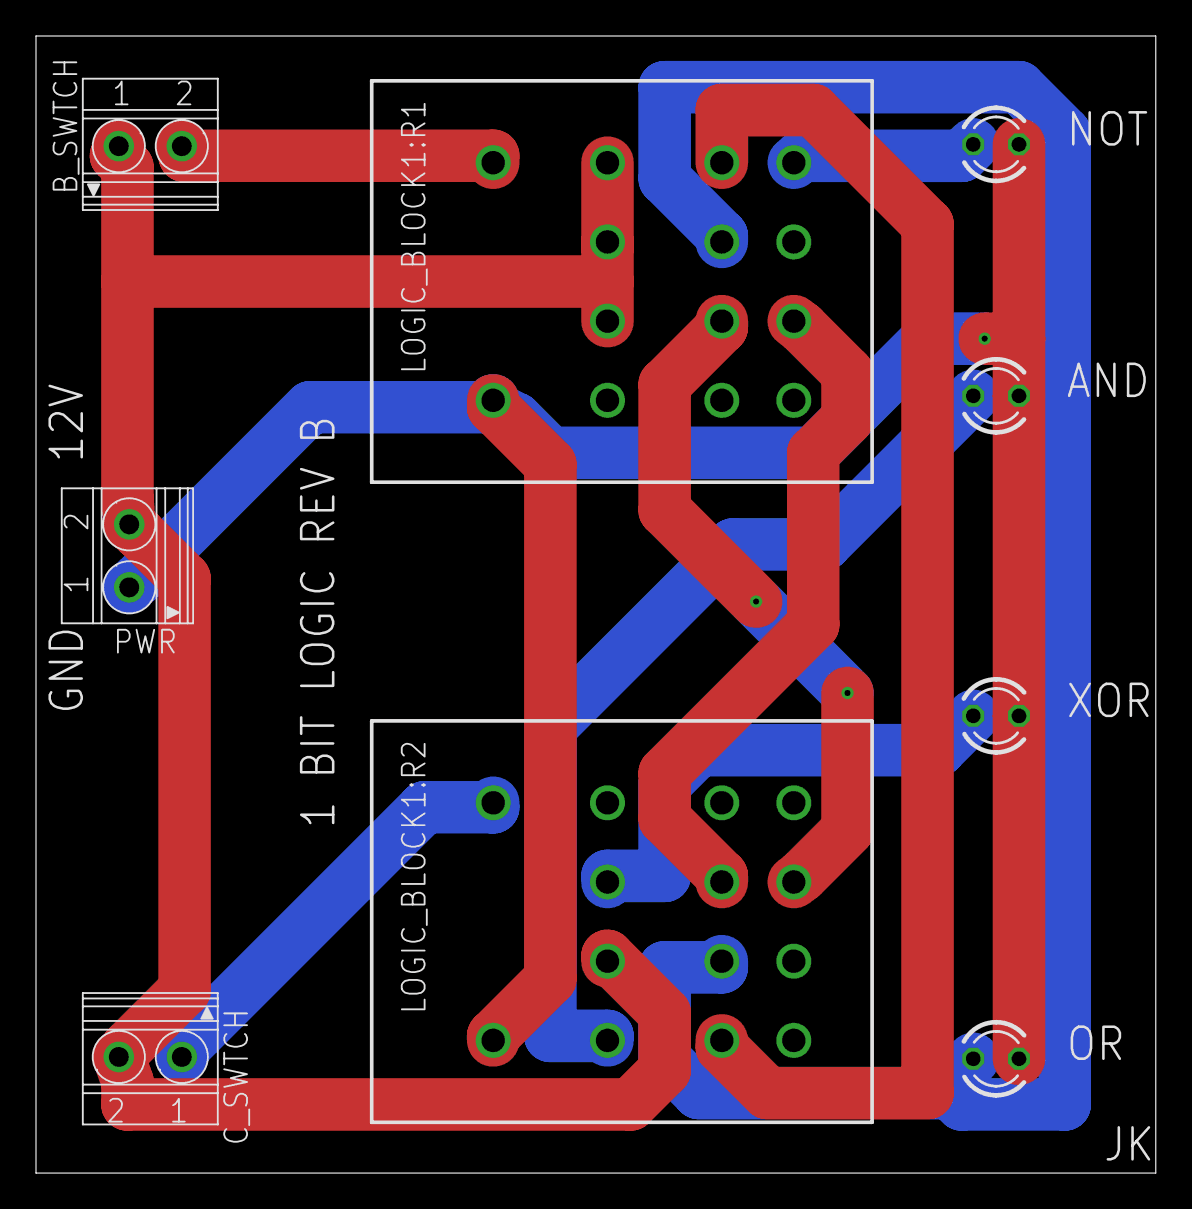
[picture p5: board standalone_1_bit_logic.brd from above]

Board: 2 copper layers, 62.2 x 63.2 mm, 9 parts (0 on the bottom side), 11 nets.

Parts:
AND_LED: LED3MM
B_SWTCH: SWTCH_BLCK; 1751248
C_SWTCH: SWTCH_BLCK; 1751248
LOGIC_BLOCK1:R1, LOGIC_BLOCK1:R2: PT571R06; PT-4
NOT_LED: LED3MM
OR_LED: LED3MM
PWR: 1751248
XOR_LED: LED3MM

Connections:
+12V: B_SWTCH.1, C_SWTCH.2, LOGIC_BLOCK1:R1.21, LOGIC_BLOCK1:R1.31, LOGIC_BLOCK1:R1.41, LOGIC_BLOCK1:R2.21, PWR.2
AND: AND_LED.A, LOGIC_BLOCK1:R2.11
B: B_SWTCH.2, LOGIC_BLOCK1:R1.A2
C: C_SWTCH.1, LOGIC_BLOCK1:R2.A2
GNDA: AND_LED.K, LOGIC_BLOCK1:R1.A1, LOGIC_BLOCK1:R2.A1, NOT_LED.K, OR_LED.K, PWR.1, XOR_LED.K
LOGIC_BLOCK1:N$1: LOGIC_BLOCK1:R1.24, LOGIC_BLOCK1:R2.32
LOGIC_BLOCK1:N$2: LOGIC_BLOCK1:R1.44, LOGIC_BLOCK1:R2.14
LOGIC_BLOCK1:N$3: LOGIC_BLOCK1:R1.22, LOGIC_BLOCK1:R2.34
NOT: LOGIC_BLOCK1:R1.42, NOT_LED.A
OR: LOGIC_BLOCK1:R1.34, LOGIC_BLOCK1:R2.24, OR_LED.A
XOR: LOGIC_BLOCK1:R2.31, XOR_LED.A

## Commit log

2017-06-07 Initial checkin
    [1 bit adder.sch, 1 bit logic block.sch, 4_bit_ALU.sch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]
2017-06-08 Fixing GND terminal on relay
    [relay_nice_layout.sch]
2017-06-08 Removing WIP adder
    [1 bit adder.sch, 4_bit_ALU.sch]
2017-06-08 Fixed wiring for 1 bit logic block
    [1 bit logic block.sch]
2017-06-08 Removing bad board and updating with correct logic block
    [standalone_1_bit_logic.brd, standalone_1_bit_logic.sch]
2017-06-08 Removing B and C LEDs since relays have indicator LEDs
    [standalone_1_bit_logic.sch]
2017-06-09 Adding 1 bit logic block rev B
    [standalone_1_bit_logic.brd, standalone_1_bit_logic.sch]
2017-08-27 Adding Adafruit's BeagleBone cape template
    [BeagleBoneTemplace.brd, BeagleBoneTemplace.sch]
2017-08-27 Quick start of 4bit ALU controller cape
    [4bit_ALU_Cape.brd, 4bit_ALU_Cape.sch]
2017-08-27 Pretty high level outline for ALU
    [4_bit_ALU.brd, 4_bit_ALU.sch]
2017-09-03 Adding HONGFA SPST and SPDT PCB-mount relays
2017-09-10 Adding connectors and diodes to library
2017-09-10 Adding coil-suppressed relay as reusable component
    [relay_w_diodes.brd, relay_w_diodes.sch]
2017-09-10 WIP: 4bit ALU. Input and 3-to-8 decoder
    [4_bit_ALU.brd, 4_bit_ALU.sch]
2017-10-01 Creating re-usable suppressed relay components w/ vertical diodes
    [4PDTrelay_nice_layout.sch, 4PDTrelay_w_diodes.brd, 4PDTrelay_w_diodes.sch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]
2017-10-01 Adding 3 and 4 pin single-row connectors
2017-10-02 WIP: start 4-bit Arithmetic Unit
    [4bit Arithmetic Unit.sch]
2017-10-03 Finishing 4bit AU
    [4bit Arithmetic Unit.sch]
2017-10-03 WIP: starting 4bit AU board. TODO: text and overlap checking
    [4bit Arithmetic Unit.brd]
2017-10-03 Finishing 4bit AU. Text is actually correct when it appears offset. Worth doing a logical double-check
    [4bit Arithmetic Unit.brd, 4bit Arithmetic Unit.sch]
2017-10-04 Finishing 4bit LU. Text is actually correct when it appears offset. Worth doing a logical double-check
    [4bit Logic Unit.brd, 4bit Logic Unit.sch]
2017-10-05 Prettier dual rail adder
    [4bit Arithmetic Unit.brd, 4bit Arithmetic Unit.sch]
2017-10-06 Adding new connector, making existing ones consistent
2017-10-06 Using updated connectors
    [4bit Arithmetic Unit.brd, 4bit Arithmetic Unit.sch, 4bit Logic Unit.brd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]
2017-12-02 Adding register board (WIP)
    [4bit Register Board.brd, 4bit Register Board.sch]
2017-12-02 Defining input signals for LU
    [4bit Logic Unit.brd]
2017-12-02 Minor formatting changes
    [4bit Arithmetic Unit.brd, 4bit Arithmetic Unit.sch]
2018-01-28 Adding TMP registers back into Register Board
    [4bit Register Board.brd, 4bit Register Board.sch]
2018-01-29 Adding 4 pin female header
2018-01-29 Re-arranging pins for high-side power switch
2018-01-29 WIP: skeleton of BBB test board
    [BBBTestCape.sch]
2018-01-30 Renaming power switch pins for consistency
2018-01-30 Finishing BBB Connection Test Board Rev A
    [BBBTestCape.brd, BBBTestCape.sch]
2018-03-13 Correcting footprint for SPST and SPDT relays
    [SPDTrelay_w_diodes.brd, SPDTrelay_w_diodes.sch, SPSTrelay_w_diodes.brd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]
2018-03-15 Adding 4.7k resistor. Shrinking 1N4007 diode footprint
2018-03-15 Shrinking 1N5359 diode footprint
2018-03-15 Updating components with latest library updates
    [4PDTrelay_w_diodes.brd, 4PDTrelay_w_diodes.sch, SPDTrelay_w_diodes.brd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]
2018-03-18 Ensuring components have most up-to-date part footprints
    [4PDTrelay_w_diodes.brd, 4PDTrelay_w_diodes.sch, SPDTrelay_w_diodes.brd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]
2018-03-18 WIP: Starting BBB Connection Test Board rev B. Added MCP23017
    [BBBTestCape.brd, BBBTestCape.sch]
2018-03-18 WIP: starting layout of BBB conn. test board rev B
    [BBBTestCape.brd, BBBTestCape.sch]
2018-03-19 Almost finished with Rev B of connector board. Comestic changes only
    [BBBTestCape.brd, BBBTestCape.sch]
2018-03-19 Adding pull down resistors for inputs to MCP23017
    [BBBTestCape.brd, BBBTestCape.sch]
2018-03-19 Ensuring part names are in tName layer so they appear on silkscreen
2018-03-19 Finishing touches of BBB Connection test Rev B board. Awaiting final review
    [BBBTestCape.brd, BBBTestCape.sch]
2018-03-21 Finalize BBB Connection Test Board Rev B. Sending this version to fab.
    [BBBTestCape.brd, BBBTestCape.sch]
2018-06-06 The AU opcode wires were switched
    [4bit Arithmetic Unit.brd, 4bit Arithmetic Unit.sch]
2018-06-06 Fixing AU subtraction CARRY bug
    [4bit Arithmetic Unit.brd, 4bit Arithmetic Unit.sch]
2018-10-27 WIP: Starting 2bit register board for testing
    [2bitRegisterBoard.sch]
2018-10-27 Compatibility updates (should be no functional changes)
    [4PDTrelay_w_diodes.sch, 4bit Register Board.brd, 4bit Register Board.sch]
2018-11-04 Completed 2bit Register Board Rev A. Sent to OSH Park
    [2bitRegisterBoard.brd, 2bitRegisterBoard.sch]
2018-12-30 Little extra spacing between holes for easier soldering of 1N5359
2018-12-30 Cleanup and removal of obsolete boards
    [4_bit_ALU.brd, 4_bit_ALU.sch, 4bit_ALU_Cape.brd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]
2018-12-30 Update latest library and add capacitor to power block
    [4bit Arithmetic Unit.sch, 4bit Logic Unit.sch]
2018-12-30 Remove unnecessary boards
    [4bit Arithmetic Unit.brd, 4bit Logic Unit.brd, 4bit Register Board.brd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]
